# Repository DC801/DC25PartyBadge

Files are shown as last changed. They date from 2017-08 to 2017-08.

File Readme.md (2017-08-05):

# DC801_DC25PartyBadge
Party badge and BLE hardware board

PARTY BADGE!

Photo credits to [Cat Murdock](https://twitter.com/catmurd0ck), thank you!

# Hardware
 - **Rigado BMD-300** Bluetooth low energy based on a Nordic nRF52832
   - 16MHz ARM® Cortex™ M4F CPU, 512kB of flash memory, 64kB RAM
   - [https://www.rigado.com/product/bmd-300/](https://www.rigado.com/product/bmd-300/)
 ***
 - **Lots of I/O**
   - 2 RGB LEDs (_eyes_)
   - 7 yellow LEDs (_helmet_)
   - 6 red LEDs (_helmet wings_)
   - Speaker
   - 4 buttons
   - 2 capacitive 'touch' buttons (_for you to discover_)
   - SPI LCD screen
   - Selected pin breakouts
   - JTAG interface
   - Micro USB - for charging only
 ***
 - A MCP73831 LiPo battery charger
 - Kickass silkscreen

Board design is in Eagle

See the [Hardware](/Hardware) directory for more info, schematics and etc

# Software
Environment is Eclipse with the GNU ARM GCC
Need a J-Link Segger JTAG programmer
Uses the softdevice s132

See the [Software](/Software) directory for more info

# What's it do?

Awesome **things**, that's what!  See the [Software](Software) directory for more information.

# More info

Follow [@rushan_ee](http://twitter.com/rushan_ee) or [@hamster](http://twitter.com/hamster) for updates

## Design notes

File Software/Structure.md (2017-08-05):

# Program Structure

The program flow starts in boot.c.  From here, the board is initialized and the 'test' entry button is checked to see if we should jump to the test routine or to the user app.

The test routine is in test.c.  The user app is in app.c

Functions that abstract hardware are in their own files, such as lcd.c, led.c, etc

system.h should be included in all files.  It pulls in the headers for all the hardware abstractions to make it easy for you to interact with the hardware.

If you add a new source file, I suggest the follwing:

 - Create both a .c and a .h
 - Use the .h to declare your functions and any enums or defines you want to share
 - Include the system.h first in your .c
 - Add the .h to system.h if and only if other modules will want to call the functions in your code - that is, if you are creating a re-usable routine as opposed to say a game or something
 - Add the .c to the Makefile with the other .c files or else it will not get compiled

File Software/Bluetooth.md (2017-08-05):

# DC25 Bluetooth Protocol

So you might have noticed that multiple badges talked to each other this year.  How did we do that?  Well, the magic is in the BLE advertising packet.

This packet can be up to 31 bytes long, and consists of a series of 'blocks'.  Each block starts with a byte that indicates how many bytes follow in this block, next byte is the block type, then the rest of the bytes are the block content.

The key parts of the DC25 protocol are the Appearance value, which must be DC19, and the manufacturer block, which defines which badge this is.  The rest of the packet can be whatever you want it to be.

Here's a visual of a packet that my DC801 badge broadcasted:

Advertising Layout

Let's break this down:

General notes:  This is the order the DC801 badge sent the blocks, but in reality the order doesn't matter.

First off, Appearance. 4 total bytes, but the length byte doesn't count, so 03 bytes long.  Type is 0x19 to indicate this is a BLE Appearance block, then the Appearance ID of DC19

Next up, Flags.  The Flags mark what kind of advertisement this is.  With our flags of 06 we indicate we are general connectable and that we'll show up in bluetooth scans.  Open your phone and look for nearby devices - your DC801 badge will show up there.  We don't offer any actual services, so connecting to the badge is a bit of a honeypit to slow down people attempting to figure out the game protocol.

Next block, Manufacturer.  This block is a little special.  The first two bytes is the manufacturer ID, which is byte swapped 'on the wire' as it were: 0108 is 0801.  Some groups actually registered with the BLE group and got a real ID - check out Bender or Queercon.  We didn't get the paperwork done in time, so we used a fake ID that was not in use for 0801.  Now, there are some bytes that follow.  Those bytes can be any length (up to the 31 total, remember), and can mean anything you want them to mean.  In our case:

0108 - DC801 is the manufacturer
70656c6c65740000 - ASCII string, your offensive vector - mine is pellet.  It is always 8 chars, if less, it is padded
0034 - The 00 is ignored on user badges, and the 34 is the random number you are broadcasting for the game.

If the OV is HELGABAH, then the 0034 is treated as a command from one of the master badges.  Two commands are defined: reset badge, and party mode:

* 0011 - Reset badge at next boot - useful for resetting a room of defaults to try to normalize the game
* 0142 - Enable party mode - Flashes the LEDs and shows PARTY on the screen, we had a few masters at the party to do this

Last block is a type 09, which is the Long Name.  This part of the BLE stack will show up as the name if you scan for a device.  Again, it's 8 chars, always, padded with 00 if shorter.  Other badges didn't even look at this, it was just for showing up in bluetooth scans.  68616d7374657200 is ASCII 'hamster'.

## The Game

So how did the game work?

At bootup and each time the game is played, a random 8 bit number is generated.  This is added a min time define, which was 500 seconds.  A counter ticks this down, and once it hits zero, the game is played again.

Each time the images cycled through, a new random number is generated for the OV broadcast.  Once the game play function is run, that number is held, and compared against whatever the last badge broadcast we received was, and if ours is lower, we lose.  If we lose, we generated another number.  If it was below 200, we would then swap our OV to whatever that other badge was broadcasting - this was so that if someone figured it out and always sent 255, there was always a chance that you wouldn't lose to them.

After all that, an image is shown win or lose, then back to the normal shout-out cycle.

Master badges did not play the game, they always kept their vector.  This was to try to normalize the game away from the default value, for people that refused to set a vector.  The default was \_Helga\_.  I'm also told some people ended up with \_Helga\_ when they turned on the badge - it could be possible there was some flash corruption or a race condition on reading the flash there.  Ooops!

How did the game work for you?  Let me know!  [@hamster](http://twitter.com/hamster)

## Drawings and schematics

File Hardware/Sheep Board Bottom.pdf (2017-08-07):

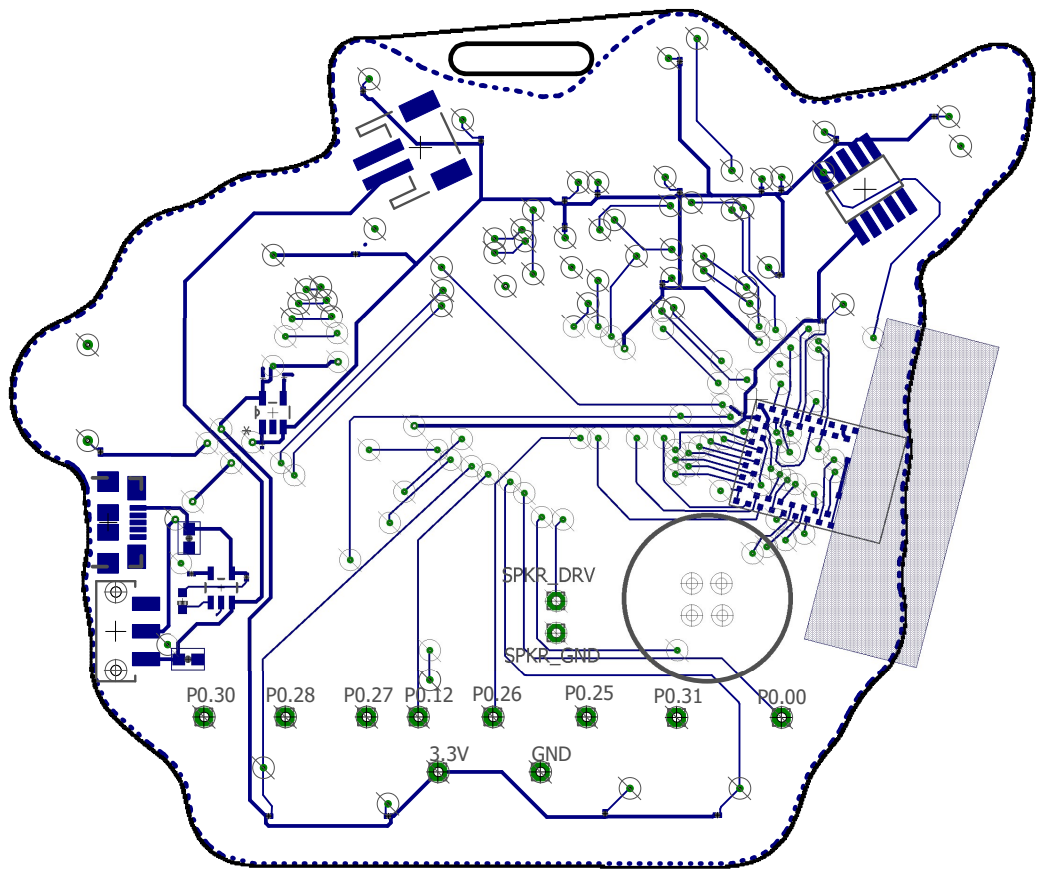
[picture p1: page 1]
GND

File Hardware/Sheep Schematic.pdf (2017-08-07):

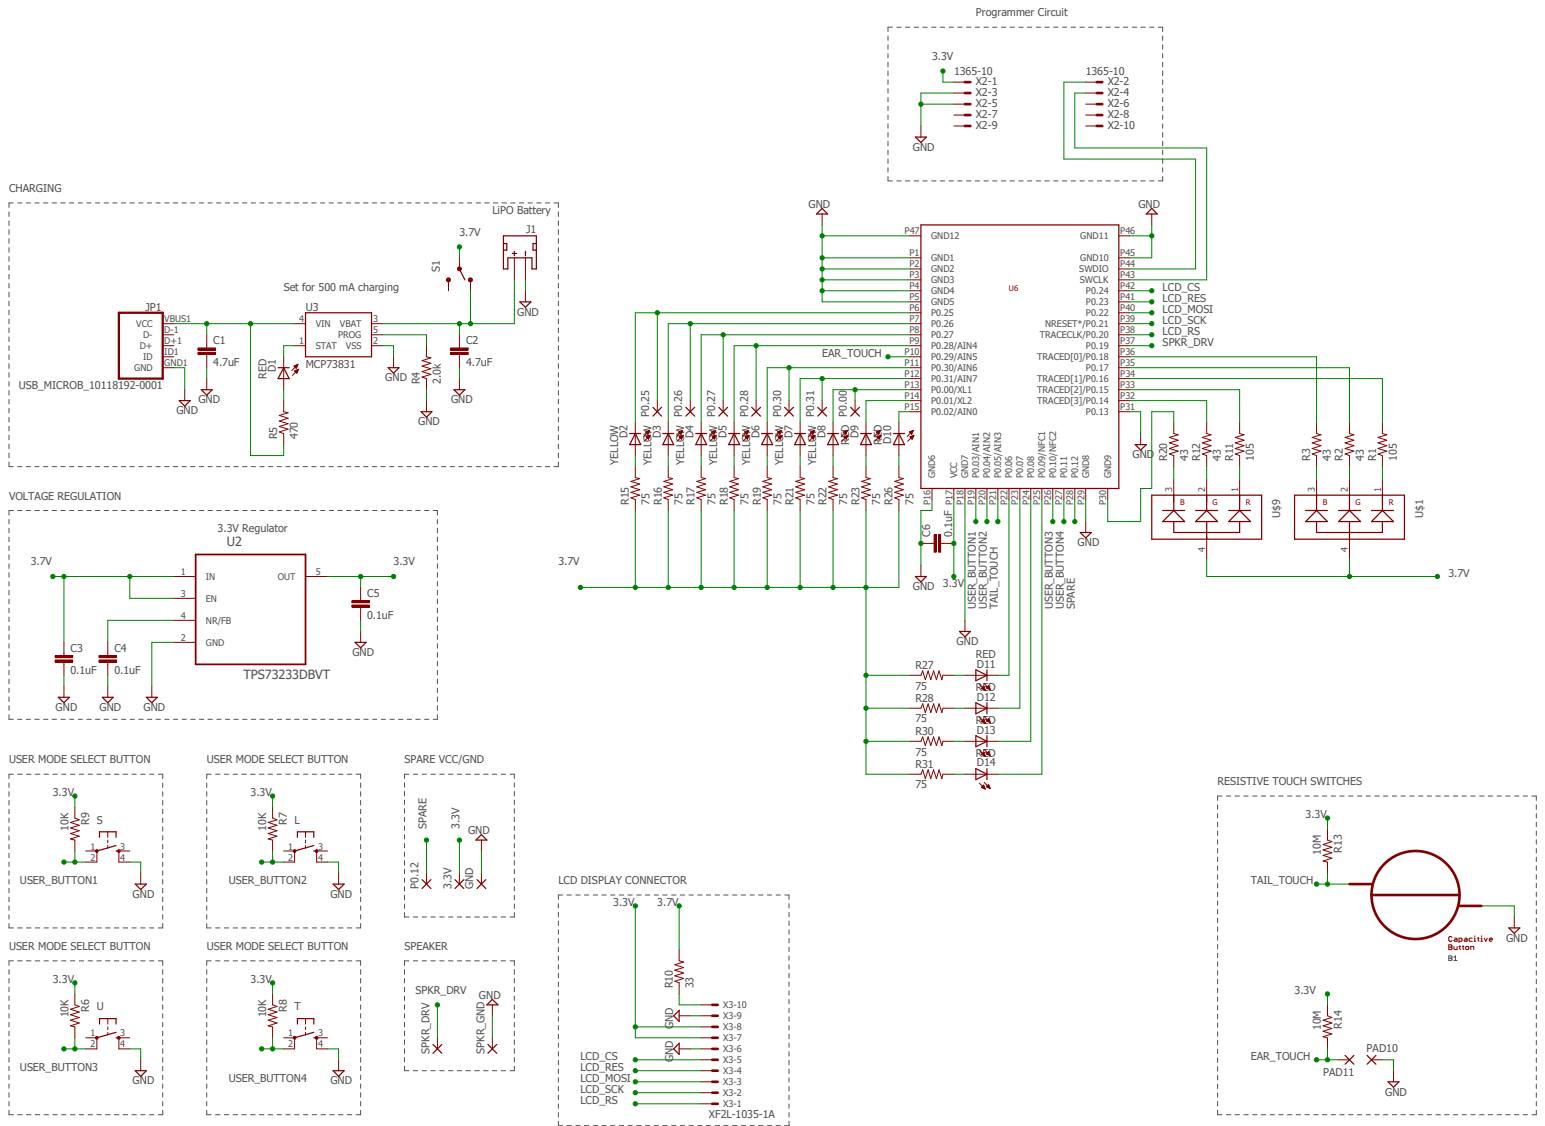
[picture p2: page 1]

USER MODE SELECT BUTTON

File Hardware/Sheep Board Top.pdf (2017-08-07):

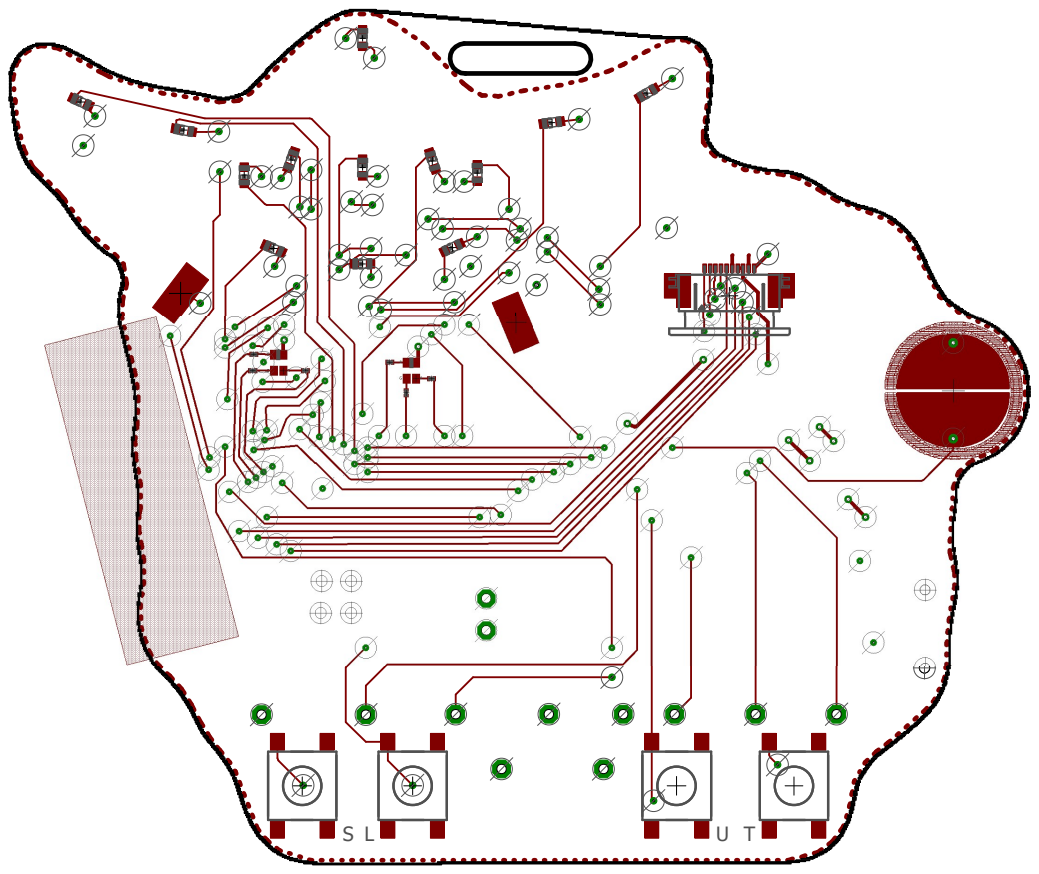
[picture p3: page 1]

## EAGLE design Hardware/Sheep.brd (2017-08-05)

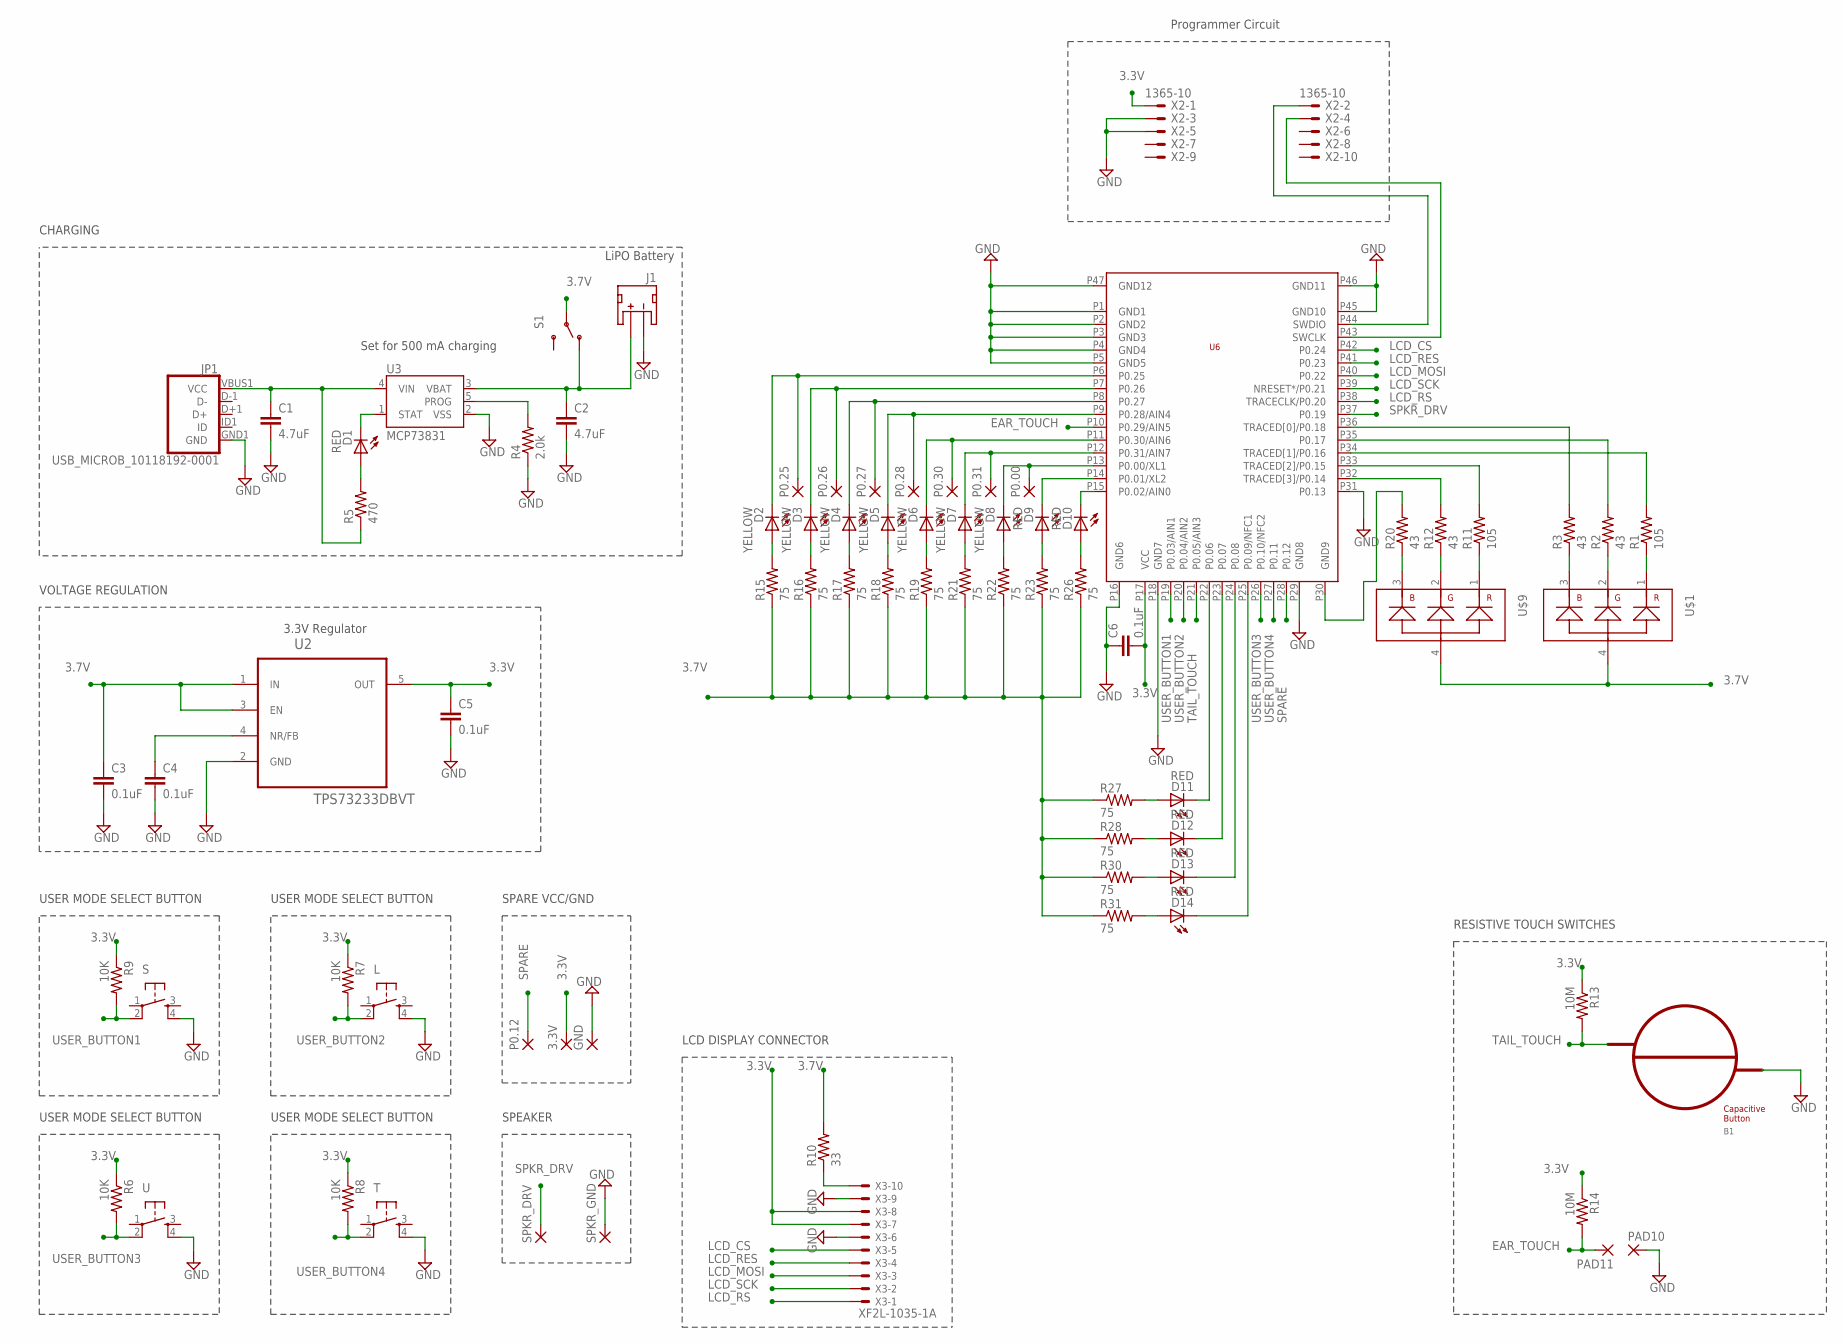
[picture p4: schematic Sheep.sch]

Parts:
3.3V: 1,6/0,8
B1: BUTTON_ACTIVE_DUAL; BUTTON_ACTIVE_DUAL_10MM
C1, C2: 4.7uF; 0603-CAP
C3, C4, C5, C6: 0.1uF; C0201
D1, D9, D10, D11, D12, D13, D14: RED; CHIP-LED0603
D2, D3, D4, D5, D6, D7, D8: YELLOW; CHIP-LED0603
GND: 1,6/0,8
J1: JST_2MM_MALE; JST-2-SMD
JP1: USB_MICROB_10118192-0001; USB-B-MICRO-SMD_V03
L: DTSM-6
P0.00, P0.12, P0.25, P0.26, P0.27, P0.28, P0.30, P0.31: 1,6/0,8
PAD10, PAD11: SMD5; SMD2,54-5,08
R1, R11: 105; R0201
R2, R3, R12, R20: 43; R0201
R4: 2.0k; R0201
R5: 470; R0201
R6, R7, R8, R9: 10K; R0201
R10: 33; R0201
R13, R14: 10M; R0201
R15, R16, R17, R18, R19, R21, R22, R23, R26, R27, R28, R30, R31: 75; R0201
S: DTSM-6
S1: SWITCH-SPDTSMD2; SWITCH-SPDT-SMD
SPKR_DRV: 1,6/0,8
SPKR_GND: 1,6/0,8
T: DTSM-6
U: DTSM-6
U2: TPS73233DBVT; SOT95P280X145-5N
U3: MCP73831; SOT23-5
U6: BMD-300
U$1, U$9: RGB; 0606
X2: 1365-10
X3: XF2L-1035-1A; 52745-1090

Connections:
3.3V: 3.3V.1, C5.1, C6.2, R6.1, R7.1, R8.1, R9.1, R13.1, R14.1, U2.5 (OUT), U6.P17 (VCC), X2.1, X3.7, X3.8
3.7V: C3.1, R10.2, R15.1, R16.1, R17.1, R18.1, R19.1, R21.1, R22.1, R23.1, R26.1, R27.1, R28.1, R30.1, R31.1, S1.2, U2.1 (IN), U2.3 (EN), U$1.4, U$9.4
5.0V: C1.1, JP1.VBUS1 (VCC), R5.1, U3.4 (VIN)
EAR_TOUCH: PAD11.1, R14.2, U6.P10 (P0.29/AIN5)
GND: B1.Q1, C1.2, C2.2, C3.2, C4.2, C5.2, C6.1, GND.1, J1.1 (-), JP1.GND1 (GND), L.4, PAD10.1, R4.1, S.4, SPKR_GND.1, T.4, U.4, U2.2 (GND), U3.2 (VSS), U6.P1 (GND1), U6.P2 (GND2), U6.P3 (GND3), U6.P4 (GND4), U6.P5 (GND5), U6.P16 (GND6), U6.P18 (GND7), U6.P29 (GND8), U6.P31 (P0.13), U6.P45 (GND10), U6.P46 (GND11), U6.P47 (GND12), X2.3, X2.5, X3.6, X3.9
LCD_CS: U6.P42 (P0.24), X3.5
LCD_MOSI: U6.P40 (P0.22), X3.3
LCD_RES: U6.P41 (P0.23), X3.4
LCD_RS: U6.P38 (TRACECLK/P0.20), X3.1
LCD_SCK: U6.P39 (NRESET*/P0.21), X3.2
unnamed: R2.2, U6.P35 (P0.17)
unnamed: R3.2, U6.P36 (TRACED[0]/P0.18)
unnamed: R11.2, U6.P33 (TRACED[2]/P0.15)
unnamed: D6.C, P0.30.1, U6.P11 (P0.30/AIN6)
unnamed: D2.C, P0.25.1, U6.P6 (P0.25)
unnamed: U6.P44 (SWDIO), X2.2
unnamed: R20.2, U6.P30 (GND9)
unnamed: D11.C, U6.P22 (P0.06)
unnamed: D12.C, U6.P23 (P0.07)
unnamed: U6.P43 (SWCLK), X2.4
unnamed: R1.2, U6.P34 (TRACED[1]/P0.16)
unnamed: R1.1, U$1.1
unnamed: R2.1, U$1.2
unnamed: R3.1, U$1.3
unnamed: D3.C, P0.26.1, U6.P7 (P0.26)
unnamed: D13.C, U6.P24 (P0.08)
unnamed: D5.C, P0.28.1, U6.P9 (P0.28/AIN4)
unnamed: D7.C, P0.31.1, U6.P12 (P0.31/AIN7)
unnamed: D8.C, P0.00.1, U6.P13 (P0.00/XL1)
unnamed: D9.C, U6.P14 (P0.01/XL2)
unnamed: D10.C, U6.P15 (P0.02/AIN0)
unnamed: D14.C, U6.P25 (P0.09/NFC1)
unnamed: R12.2, U6.P32 (TRACED[3]/P0.14)
unnamed: R4.2, U3.5 (PROG)
unnamed: D11.A, R27.2
unnamed: D12.A, R28.2
unnamed: D13.A, R30.2
unnamed: D14.A, R31.2
unnamed: R10.1, X3.10
unnamed: D1.A, R5.2
unnamed: D1.C, U3.1 (STAT)
unnamed: R11.1, U$9.1
unnamed: R12.1, U$9.2
unnamed: D2.A, R15.2
unnamed: D3.A, R16.2
unnamed: D4.A, R17.2
unnamed: D5.A, R18.2
unnamed: D6.A, R19.2
unnamed: D7.A, R21.2
unnamed: D8.A, R22.2
unnamed: C4.1, U2.4 (NR/FB)
unnamed: D9.A, R23.2
unnamed: D10.A, R26.2
unnamed: R20.1, U$9.3
unnamed: D4.C, P0.27.1, U6.P8 (P0.27)
SPARE: P0.12.1, U6.P28 (P0.12)
SPKR_DRV: SPKR_DRV.1, U6.P37 (P0.19)
TAIL_TOUCH: B1.Q2, R13.2, U6.P21 (P0.05/AIN3)
USER_BUTTON1: R9.2, S.2, U6.P19 (P0.03/AIN1)
USER_BUTTON2: L.2, R7.2, U6.P20 (P0.04/AIN2)
USER_BUTTON3: R6.2, U.2, U6.P26 (P0.10/NFC2)
USER_BUTTON4: R8.2, T.2, U6.P27 (P0.11)
VBAT1: C2.1, J1.2 (+), S1.1 (O), U3.3 (VBAT)

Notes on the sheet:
LiPO Battery
Set for 500 mA charging
3.3V Regulator
CHARGING
VOLTAGE REGULATION
USER MODE SELECT BUTTON
Programmer Circuit
LCD DISPLAY CONNECTOR
SPARE VCC/GND
SPEAKER
RESISTIVE TOUCH SWITCHES

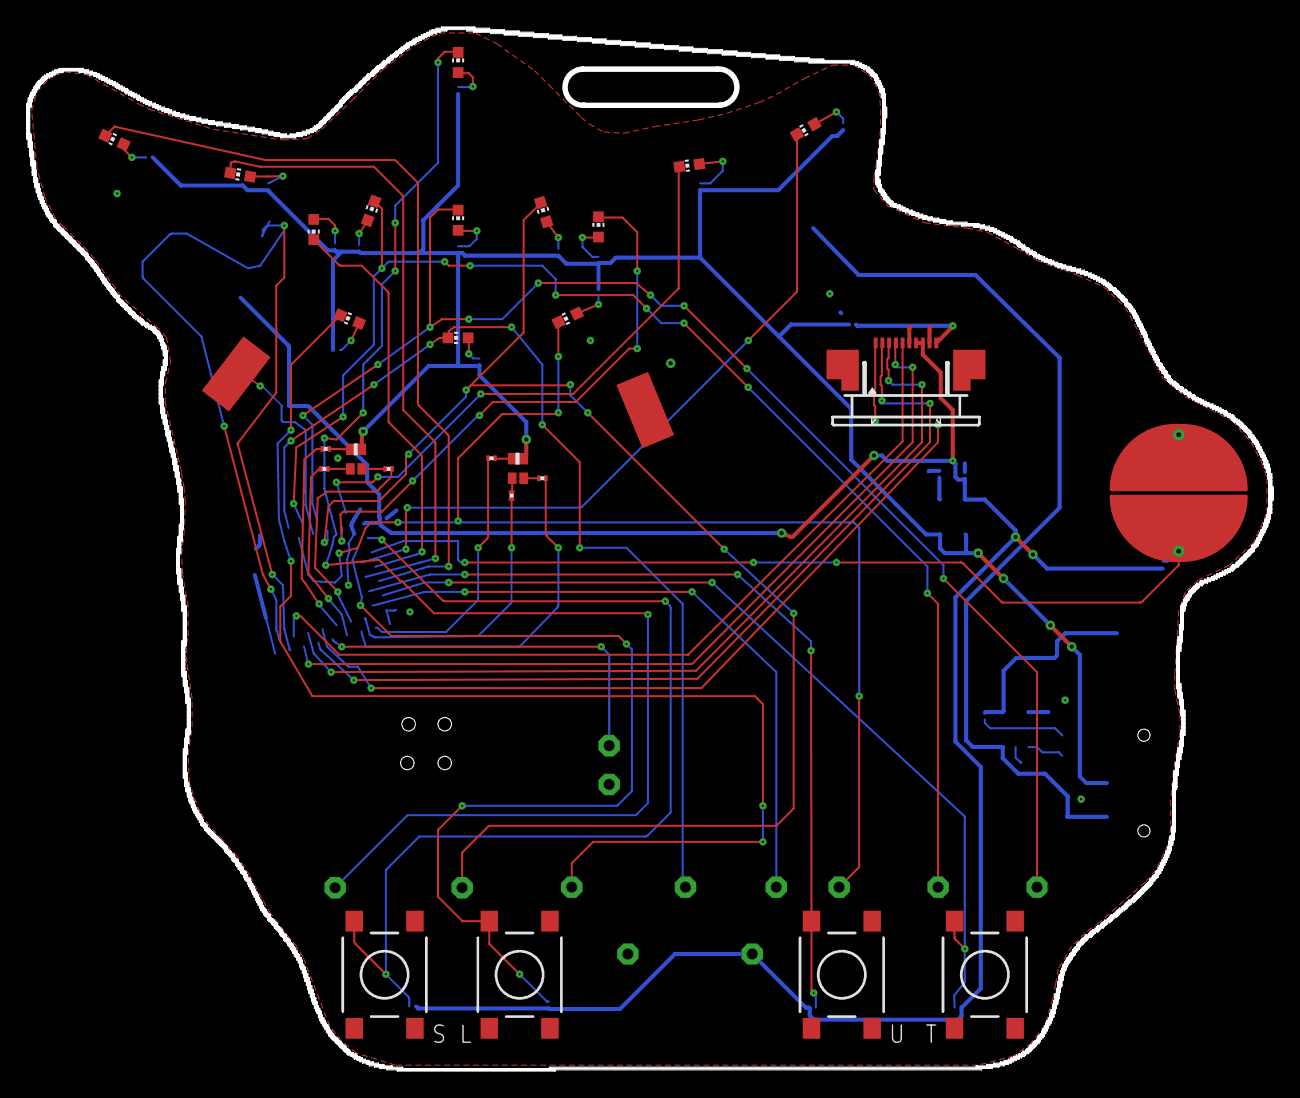
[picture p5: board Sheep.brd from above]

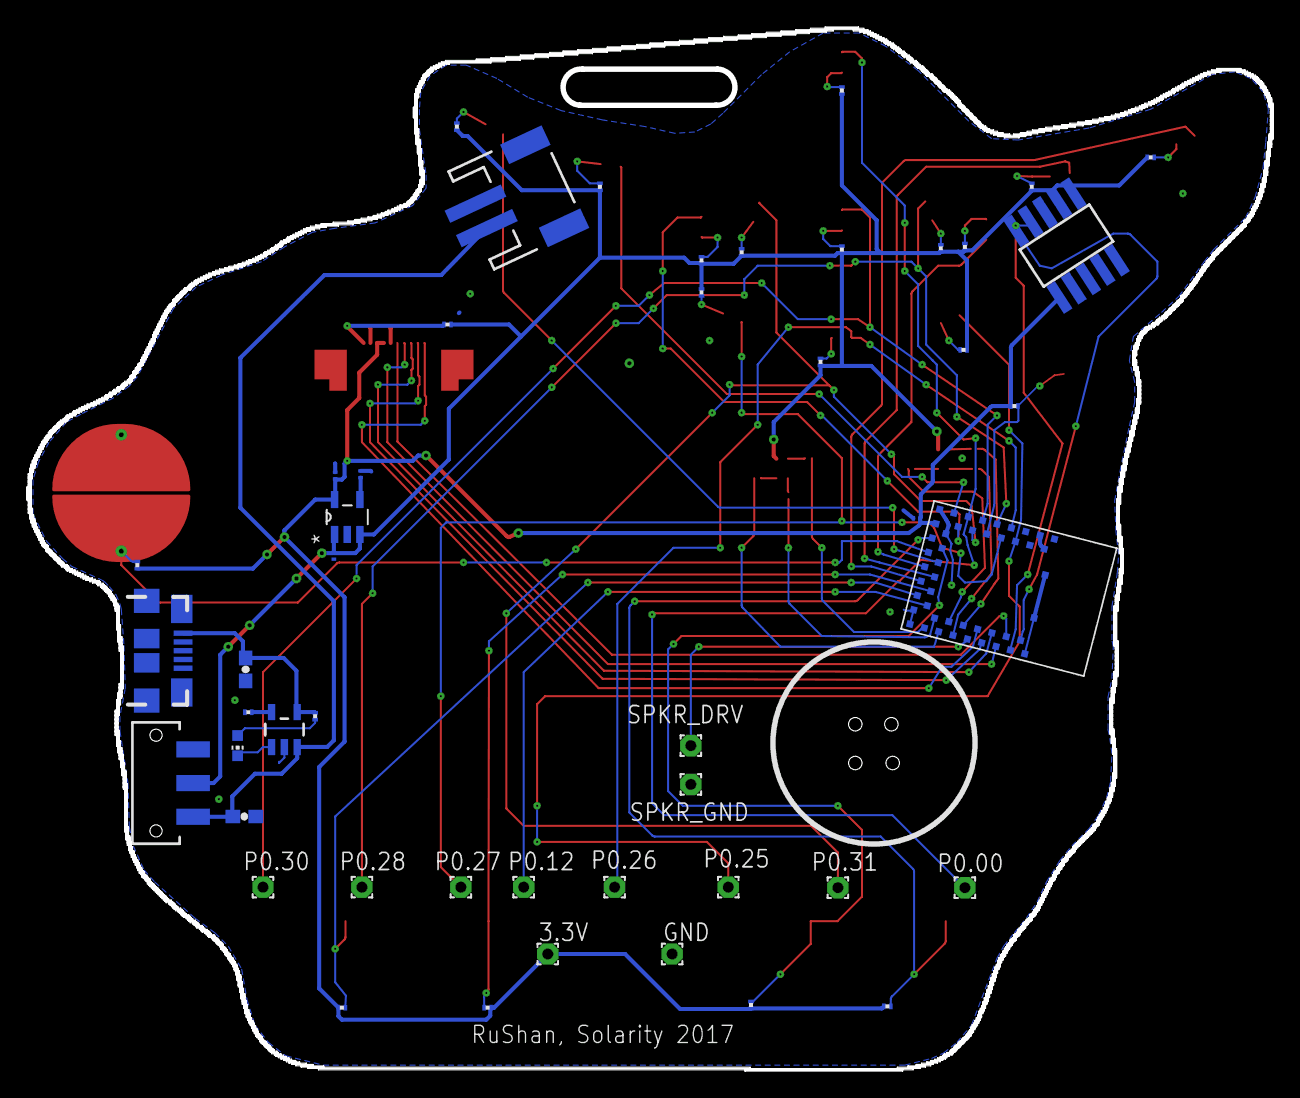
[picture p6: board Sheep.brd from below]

Board: 2 copper layers, 92.5 x 77.5 mm, 77 parts (48 on the bottom side), 63 nets.

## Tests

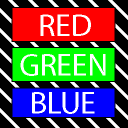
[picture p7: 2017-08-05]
Software/bmp/images-in/test_colors.bmp

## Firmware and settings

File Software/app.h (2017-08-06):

/*
 * @file app.h
 * @date May 24, 2017
 * @author hamster
 *
 */

#ifndef APP_H_
#define APP_H_

void run_app_mode(bool setup);
void badgeSetup(void);
void sawBadge(uint16_t id);
void addSeenManufacturer(uint16_t id);
bool getSeenManufacturer(uint16_t id);
void clearSeenManufacturer(void);
void clearGameData(void);
void updateGameData(char* vector, uint8_t diceRoll);
void updateCommandData(uint16_t flags);
void clearCommandData(void);
void playGame(void);
void protoReset(void);
void masterCommandHandle(void);

typedef struct {
	bool crypto;
	bool queercon;
	bool dc801;
	bool dc503;
	bool bender;
	bool b_d;
	bool dczia;
	bool dczia_shotbot;
} SEEN_MANUFACTURER;

typedef struct {
	uint8_t diceRoll;
	uint16_t waitTime;
} INFECTION_PARAMS;

typedef struct {
	char username[9];
	char vector[9];
} CONFIG_PARAMS;

typedef struct {
	char vector[9];
	uint8_t diceRoll;
	bool nearby;
} GAME_DATA;

typedef struct {
	bool partyMode;
	bool fullReconfig;
	bool sendingCommand;
} COMMAND_DATA;

extern volatile INFECTION_PARAMS infectionParams;
extern CONFIG_PARAMS configParams;


#define MIN_WAIT_TIME 500  // Infection game run every these many seconds + rand number
#define DEFAULT_USER	"801SHEEP"
#define DEFAULT_VECTOR	"_Helga_"

#define MASTER_BADGE	false

#endif /* APP_H_ */

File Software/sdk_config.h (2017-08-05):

/*
 * @file sdk_config.h
 *
 * @date May 25, 2017
 * @author hamster
 *
 * This file configures the SDK to enable various components to compile
 *
 */

#ifndef SDK_CONFIG_H
#define SDK_CONFIG_H
// <<< Use Configuration Wizard in Context Menu >>>\n
#ifdef USE_APP_CONFIG
#include "app_config.h"
#endif

// <h> nRF_BLE 

//==========================================================
// <q> BLE_ADVERTISING_ENABLED  - ble_advertising - Advertising module
 

#ifndef BLE_ADVERTISING_ENABLED
#define BLE_ADVERTISING_ENABLED 0
#endif

// <q> BLE_DTM_ENABLED  - ble_dtm - Module for testing RF/PHY using DTM commands
 

#ifndef BLE_DTM_ENABLED
#define BLE_DTM_ENABLED 0
#endif

// <q> BLE_RACP_ENABLED  - ble_racp - Record Access Control Point library
 

#ifndef BLE_RACP_ENABLED
#define BLE_RACP_ENABLED 0
#endif

// <q> NRF_BLE_QWR_ENABLED  - nrf_ble_qwr - Queued writes support module (prepare/execute write)
 

#ifndef NRF_BLE_QWR_ENABLED
#define NRF_BLE_QWR_ENABLED 0
#endif

// <q> PEER_MANAGER_ENABLED  - peer_manager - Peer Manager
 

#ifndef PEER_MANAGER_ENABLED
#define PEER_MANAGER_ENABLED 0
#endif

// </h> 
//==========================================================

// <h> nRF_BLE_Services 

//==========================================================
// <q> BLE_ANCS_C_ENABLED  - ble_ancs_c - Apple Notification Service Client
 

#ifndef BLE_ANCS_C_ENABLED
#define BLE_ANCS_C_ENABLED 0
#endif

// <q> BLE_ANS_C_ENABLED  - ble_ans_c - Alert Notification Service Client
 

#ifndef BLE_ANS_C_ENABLED
#define BLE_ANS_C_ENABLED 0
#endif

// <q> BLE_BAS_C_ENABLED  - ble_bas_c - Battery Service Client
 

#ifndef BLE_BAS_C_ENABLED
#define BLE_BAS_C_ENABLED 0
#endif

// <q> BLE_BAS_ENABLED  - ble_bas - Battery Service
 

#ifndef BLE_BAS_ENABLED
#define BLE_BAS_ENABLED 0
#endif

// <q> BLE_CSCS_ENABLED  - ble_cscs - Cycling Speed and Cadence Service
 

#ifndef BLE_CSCS_ENABLED
#define BLE_CSCS_ENABLED 0
#endif

// <q> BLE_CTS_C_ENABLED  - ble_cts_c - Current Time Service Client
 

#ifndef BLE_CTS_C_ENABLED
#define BLE_CTS_C_ENABLED 0
#endif

// <q> BLE_DIS_ENABLED  - ble_dis - Device Information Service
 

#ifndef BLE_DIS_ENABLED
#define BLE_DIS_ENABLED 0
#endif

// <q> BLE_GLS_ENABLED  - ble_gls - Glucose Service
 

#ifndef BLE_GLS_ENABLED
#define BLE_GLS_ENABLED 0
#endif

// <q> BLE_HIDS_ENABLED  - ble_hids - Human Interface Device Service
 

#ifndef BLE_HIDS_ENABLED
#define BLE_HIDS_ENABLED 0
#endif

// <e> BLE_HRS_C_ENABLED - ble_hrs_c - Heart Rate Service Client
//==========================================================
#ifndef BLE_HRS_C_ENABLED
#define BLE_HRS_C_ENABLED 0
#endif
#if  BLE_HRS_C_ENABLED
// <o> BLE_HRS_C_RR_INTERVALS_MAX_CNT - Maximum number of RR_INTERVALS per notification to be decoded 
#ifndef BLE_HRS_C_RR_INTERVALS_MAX_CNT
#define BLE_HRS_C_RR_INTERVALS_MAX_CNT 30
#endif

#endif //BLE_HRS_C_ENABLED
// </e>

// <q> BLE_HRS_ENABLED  - ble_hrs - Heart Rate Service
 

#ifndef BLE_HRS_ENABLED
#define BLE_HRS_ENABLED 0
#endif

// <q> BLE_HTS_ENABLED  - ble_hts - Health Thermometer Service
 

#ifndef BLE_HTS_ENABLED
#define BLE_HTS_ENABLED 0
#endif

// <q> BLE_IAS_C_ENABLED  - ble_ias_c - Immediate Alert Service Client
 

#ifndef BLE_IAS_C_ENABLED
#define BLE_IAS_C_ENABLED 0
#endif

// <q> BLE_IAS_ENABLED  - ble_ias - Immediate Alert Service
 

#ifndef BLE_IAS_ENABLED
#define BLE_IAS_ENABLED 0
#endif

// <q> BLE_LBS_C_ENABLED  - ble_lbs_c - Nordic LED Button Service Client
 

#ifndef BLE_LBS_C_ENABLED
#define BLE_LBS_C_ENABLED 0
#endif

// <q> BLE_LBS_ENABLED  - ble_lbs - LED Button Service
 

#ifndef BLE_LBS_ENABLED
#define BLE_LBS_ENABLED 0
#endif

// <q> BLE_LLS_ENABLED  - ble_lls - Link Loss Service
 

#ifndef BLE_LLS_ENABLED
#define BLE_LLS_ENABLED 0
#endif

// <q> BLE_NUS_C_ENABLED  - ble_nus_c - Nordic UART Central Service
 

#ifndef BLE_NUS_C_ENABLED
#define BLE_NUS_C_ENABLED 0
#endif

// <q> BLE_NUS_ENABLED  - ble_nus - Nordic UART Service
 

#ifndef BLE_NUS_ENABLED
#define BLE_NUS_ENABLED 0
#endif

// <q> BLE_RSCS_C_ENABLED  - ble_rscs_c - Running Speed and Cadence Client
 

#ifndef BLE_RSCS_C_ENABLED
#define BLE_RSCS_C_ENABLED 0
#endif

// <q> BLE_RSCS_ENABLED  - ble_rscs - Running Speed and Cadence Service
 

#ifndef BLE_RSCS_ENABLED
#define BLE_RSCS_ENABLED 0
#endif

// <q> BLE_TPS_ENABLED  - ble_tps - TX Power Service
 

#ifndef BLE_TPS_ENABLED
#define BLE_TPS_ENABLED 0
#endif

// </h> 
//==========================================================

// <h> nRF_Drivers 

//==========================================================
// <e> APP_USBD_ENABLED - app_usbd - USB Device library
//==========================================================
#ifndef APP_USBD_ENABLED
#define APP_USBD_ENABLED 0
#endif
#if  APP_USBD_ENABLED
// <o> APP_USBD_VID - Vendor ID  <0x0000-0xFFFF> 


// <i> Vendor ID ordered from USB IF: http://www.usb.org/developers/vendor/

#ifndef APP_USBD_VID
#define APP_USBD_VID 0
#endif

// <o> APP_USBD_PID - Product ID  <0x0000-0xFFFF> 


// <i> Selected Product ID
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

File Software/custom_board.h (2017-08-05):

/**
 *
 * @file custom_board.h
 *
 * @date May 24, 2017
 * @author hamster
 *
 * This is the custom board defines for the LEDs and etc on the DC25 badge
 *
 */

#ifndef DC801_H
#define DC801_H

#ifdef __cplusplus
extern "C" {
#endif

// LEDs definitions

// Low is active
#define LEDS_ACTIVE_STATE 0

// LED Pins

// Helmet Wings
// Right, from center
#define LED_WING_RIGHT_RED_1     1
#define LED_WING_RIGHT_RED_2     2
#define LED_WING_RIGHT_RED_3     6
// Left, from center
#define LED_WING_LEFT_RED_1      7
#define LED_WING_LEFT_RED_2      8
#define LED_WING_LEFT_RED_3      9

// Helmet
#define LED_HELMET_YELLOW_1		25
#define LED_HELMET_YELLOW_2		26
#define LED_HELMET_YELLOW_3		27
#define LED_HELMET_YELLOW_4		28
#define LED_HELMET_YELLOW_5		30
#define LED_HELMET_YELLOW_6		31
#define LED_HELMET_YELLOW_7		0

// Eyes
// Right
#define LED_EYE_RIGHT_RED		15
#define LED_EYE_RIGHT_GREEN		14
//#define LED_EYE_RIGHT_BLUE		12 // only on proto boards
#define LED_EYE_RIGHT_BLUE		13
// Left
#define LED_EYE_LEFT_RED		16
#define LED_EYE_LEFT_GREEN		17
#define LED_EYE_LEFT_BLUE		18

// Arrays to make iteration easy
// The Nordic SDK uses LEDS_LIST internally
#define LEDS_LIST { \
	LED_WING_RIGHT_RED_1, 	\
	LED_WING_RIGHT_RED_2, 	\
	LED_WING_RIGHT_RED_3,	\
	LED_WING_LEFT_RED_1,	\
	LED_WING_LEFT_RED_2,	\
	LED_WING_LEFT_RED_3,	\
	LED_HELMET_YELLOW_1,	\
	LED_HELMET_YELLOW_2,	\
	LED_HELMET_YELLOW_3,	\
	LED_HELMET_YELLOW_4,	\
	LED_HELMET_YELLOW_5,	\
	LED_HELMET_YELLOW_6,	\
	LED_HELMET_YELLOW_7,	\
	LED_EYE_RIGHT_RED,		\
	LED_EYE_RIGHT_GREEN,	\
	LED_EYE_RIGHT_BLUE,		\
	LED_EYE_LEFT_RED,		\
	LED_EYE_LEFT_GREEN,		\
	LED_EYE_LEFT_BLUE	}

#define LEDS_NUMBER    		19

// LEDs in the helmet
#define HELMET_LEDS { \
		LED_HELMET_YELLOW_1,	\
		LED_HELMET_YELLOW_2,	\
		LED_HELMET_YELLOW_3,	\
		LED_HELMET_YELLOW_4,	\
		LED_HELMET_YELLOW_5,	\
		LED_HELMET_YELLOW_6,	\
		LED_HELMET_YELLOW_7	}

#define HELMET_LEDS_NUMBER 7

static const uint32_t helmet_led_list[HELMET_LEDS_NUMBER] = HELMET_LEDS;

// LEDs in the helmet wings
#define WING_LEDS { \
		LED_WING_RIGHT_RED_1, 	\
		LED_WING_RIGHT_RED_2, 	\
		LED_WING_RIGHT_RED_3,	\
		LED_WING_LEFT_RED_1,	\
		LED_WING_LEFT_RED_2,	\
		LED_WING_LEFT_RED_3 }

#define WING_LEDS_NUMBER 6

static const uint32_t wing_led_list[WING_LEDS_NUMBER] = WING_LEDS;

// Push buttons

#define BUTTONS_NUMBER 6

#define USER_BUTTON_1       3
#define USER_BUTTON_2       4
#define USER_BUTTON_3       10
#define USER_BUTTON_4       11
#define TAIL_TOUCH			5
#define EAR_TOUCH			29

#define LONG_PRESS_MASK		0x8000

#define USER_BUTTON_1_LONG       (3  | LONG_PRESS_MASK)
#define USER_BUTTON_2_LONG       (4  | LONG_PRESS_MASK)
#define USER_BUTTON_3_LONG       (10 | LONG_PRESS_MASK)
#define USER_BUTTON_4_LONG       (11 | LONG_PRESS_MASK)
#define TAIL_TOUCH_LONG			 (5  | LONG_PRESS_MASK)
#define EAR_TOUCH_LONG			 (29 | LONG_PRESS_MASK)

#define BUTTONS_LIST { \
	USER_BUTTON_1,	\
	USER_BUTTON_2,	\
	USER_BUTTON_3,	\
	USER_BUTTON_4,	\
	TAIL_TOUCH,		\
	EAR_TOUCH	}

// Low is active
#define BUTTONS_ACTIVE_STATE	0
// Don't need a pull up
#define BUTTON_PULL				0

// Just one speaker
#define SPEAKER		19

// LCD
// The SPI ports are defined in the config/sdk_config.h
#define LCD_RESET	23

// Clock
// Low frequency clock source to be used by the SoftDevice
// We're using the internal RC osc
#define NRF_CLOCK_LFCLKSRC      {.source        = NRF_CLOCK_LF_SRC_RC, \
                                 .rc_ctiv       = 1, \
                                 .rc_temp_ctiv  = 2, \
                                 .xtal_accuracy = NRF_CLOCK_LF_XTAL_ACCURACY_20_PPM}


#ifdef __cplusplus
}
#endif

#endif // DC801_H

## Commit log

2017-08-05 Adding the final software and hardware design for the DC25 party badge
    [Sheep.brd, Sheep.sch]
2017-08-06 Fixed detection of Queercon badges - they use more than 31 bytes advertisement, which means that part of the packet is received as a scan response
    [app.h]
2017-08-07 Adding pdf versions of the schematic and board

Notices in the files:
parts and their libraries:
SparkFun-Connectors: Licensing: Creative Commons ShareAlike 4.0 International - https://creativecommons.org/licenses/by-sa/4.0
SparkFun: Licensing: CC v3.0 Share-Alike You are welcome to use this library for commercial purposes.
